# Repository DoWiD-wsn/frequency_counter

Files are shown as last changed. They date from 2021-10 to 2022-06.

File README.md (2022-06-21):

# AVR-based Frequency Counter

The AVR-based frequency counter is partly based on the project developed by [Herbert Dingfelder](http://www.herbert-dingfelder.de/?page_id=304) with some extensions and modifications.
It contains an ATmega8 responsible for measuring the frequency of a square-wave applied to one of four input channels (selectable by software) and acting as a TWI slave (I2C).
With the current design, frequencies of up to 50 MHz are measurable with a precision of 10 Hz.

The AVR-based frequency counter was developed and used as part of the [Embedded Testbench (ETB)](https://github.com/DoWiD-wsn/embedded_testbench) where it was used to measure the frequency stability of the internal clock of microcontroller units of embedded systems under different conditions such as ambient temperature and supply voltage level.

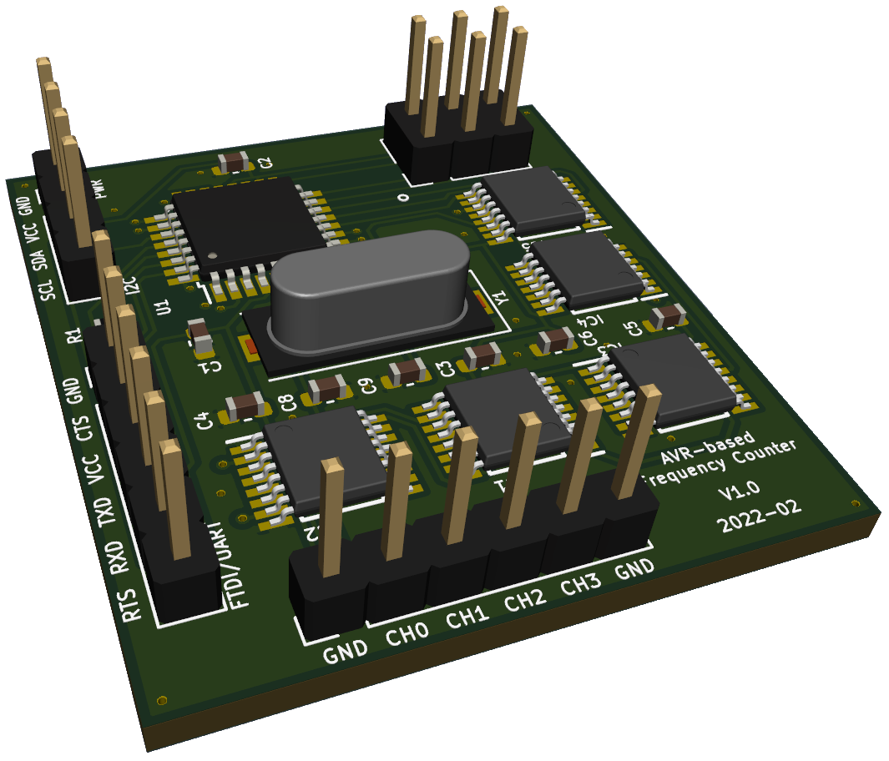
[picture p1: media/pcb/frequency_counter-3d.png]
PCB 3D (/media/pcb/frequency_counter-3d.png)


For more information on the PCB (and its design) refer to [docs/pcb_design.md](docs/pcb_design.md).

## Directory structure

```
.
├── docs                : documents
│   ├── datasheets      : datasheets of used components
│   └── pcb_design.md   : information on the PCB design
├── kicad               : KiCad files
├── media               : Miscellaneous media (images, etc.)
│   ├── evaluation      : Image of a first prototype evaluation
│   ├── i2c             : I2C register format
│   ├── pcb             : Photos and rendered images of the PCB
│   └── schematic       : SVG images of the schematics
└── source              : C code sources for the ATmega8
```

## Contents

* [Description](#description)
* [Built with](#built-with)
* [Preparation](#preparation)
* [I2C Interface](#i2c-interface)
* [Evaluation](#evaluation)
* [Contributors](#contributors)
* [Changelog](#changelog)
* [License](#license)

## Description

**Schematic** (draft):  
Schematic (/media/schematic/frequency_counter-draft.svg)

The ATmega8 is clocked with an external quartz crystal with a frequency of 4.096 MHz.
This clock signal is also used to generate a gate-enable signal for the actual frequency counting stage.
To do so, the 4.096 MHz are first divided by a 74HC4040 with a factor of 2^12 (4096) to get a 1 kHz signal that is further divided by a second 74HC4040 with a factor of 2^8 (256) to have an enable signal with a frequency of 3.90625 Hz (corresponds to an enable time of 128 ms (high level)).

The 74HC153 is used to select between four different input channels.
During the 128 ms long high period of the second 74HC4040, the signal of at the selected input channel is forwarded to the third 74HC4040.
That third 74HC4040 forms together with the ATmega8 the actual counting part, that is, both components together form a 24-bit counter that counts the number of periods of the selected input signal during the 128 ms long enable period.
Thereby, the lower 8-bit (fast portion) are counted by the 74HC4040 and, since the eight bit (Q7) triggers the ATmega8' internal 16-bit counter module, the higher 16-bit are counted internally by the ATmega8.
As the 128 ms enable signal is also connected to the external interrupt (INT0) of the ATmega8, the ATmega8 is "informed" whenever a counting period has finished and can then calculate the corresponding frequency of the input signal.
To do so, the 24-bit counter (lower 8-bit read via GPIOs and the higher 16-bit available interally) show how many periods have passed in the last 128 ms and, thus, allow to easily calculate the resulting frequency.

The measured frequency is output via the UART debug interface (default: 8N1 @9600baud).
As the ATmega8 is configured as an I2C slave (address to be defined in software; default: `0x24`), the result can also be obtained via I2C.
Additionally, the I2C interface can be used to configure the basic operation of the frequency counter such as:

* result resolution (Hz, kHz, or MHz)
* input channel (CH0, CH1, CH2, or CH3)
* sampling rate (no sampling, 3 samples, 5 samples, or 10 samples)

Additionally, the result ready flag can be read indicating whether a result is already available.
In case required, also a counter reset (clearing of all registers) can be requested via I2C.

## Built with

The entire code only depends on the basic AVR libraries (i.e., AVR libc) and can be easily compiled with the AVR GCC.
To upload the binary to the ATmega8, the [AVR-ISP](https://www.mikrocontroller.net/articles/AVR_In_System_Programmer) can be used in combination with [AVRdude](https://www.nongnu.org/avrdude/) or similar.

* [avr-gcc 5.4.0](https://gcc.gnu.org/wiki/avr-gcc) - C code library
* [avr-libc 2.0.0](https://www.nongnu.org/avr-libc/) - C code library

## Preparation

Aside from the hardware circuit, it is important to properly set the fuses of the used ATmega8.
The fuses take care of a basic configuration of the ATmega8, or more precisely, they define the clock source and some interfacing options.
For the AVR-based frequency counter, we choose to have an external crystal oscillator and at startup we will give it some clock cycles to become stable.
As stated in the [ATmega8 datasheet](https://www.microchip.com/wwwproducts/en/ATmega8), we need to have the clock selection fuses `CKSEL` set to `1111` and the start-up times fuses `SUT` set to `11`, resulting in the `low fuse byte` to be set to `0xFF` (Note: the fuse bits are active low, i.e. programmed=0, unprogrammed=1; see also [AVR Fuse Calculator](http://eleccelerator.com/fusecalc/fusecalc.php?chip=atmega8)).

In the `high fuse byte`, we leave the boot size selection bits enabled, i.e., `BOOTSZ` is `00`, and we keep the serial programming and data downloading `SPIEN` enabled (otherwise we would not be able to use the [AVR ISP](https://www.mikrocontroller.net/articles/AVR_In_System_Programmer) to flash our firmware).
Additionally, we need to program the oscillator options fuse `CKOPT` to `0` to switch the crystal from weak amplitude to full amplitude required to clock the [74HC4040](https://www.ti.com/product/SN74HC4040) counter.
As a result, we need to set the `high fuse byte` to `0xC9`.

The fuse bit values and the resulting bit pattern as well as the corresponding [AVRDUDE](https://www.nongnu.org/avrdude/) commands can be derived with one of the available [online fuse calculator](https://www.engbedded.com/fusecalc/).
In our case, the resulting AVRDUDE arguments are:  
  `-U lfuse:w:0xff:m -U hfuse:w:0xc9:m`

## I2C Interface

The AVR-based frequency counter can be used as an I2C slave.
The I2C address can be defined in software (default: 0x24).

Basically, there are four 8-bit registers available and accessible via I2C, that are:

1. Configuration register `CONFIG` (address: `0x00`; R/W)
2. Frequency LSB register `FREQ-LSB` (address: `0x01`; R)
3. Frequency MSB register `FREQ-MSB` (address: `0x02`; R)
4. Frequency extended MSB register `FREQ-XMSB` (address: `0x03`; R)

As can be seen, all registers can be read but only the `CONFIG` register allows overwriting its value; the measured frequency value can only be read.

With the `CONFIG` register, the basic operation of the frequency counter can be defined, that is, requesting a software reset, checking the result ready flag, setting the sampling rate, defining the frequency resolution, and selecting the input channel (see figure below).
The default value of the `CONFIG` register is `0x00`.

Prototype (/media/i2c/i2c_reg-config.svg)

### Reset request

The reset request bit can be used to cause a software reset of the frequency counter, that is, all counter modules and internal counter values are reset.
The configuration is not changed.

| `RST` | Effect |
|---|---|
| `0` | no effect |
| `1` | request reset |

### Result ready

The result ready flag indicates whether a frequency measurement is ready to be read.

| `RDY` | Meaning |
|---|---|
| `0` | result not available |
| `1` | result available |

### Result sampling

The frequency counter offers to possibility to sample several measurements and provide the mean average to have more stable results.
Thereby, one of four different sampling options can be selected.

| `SMP1` | `SMP0` | Sampling |
|---|---|---|
| `0` | `0` | no sampling |
| `0` | `1` | 3 samples |
| `1` | `0` | 5 samples |
| `1` | `1` | 10 samples |

### Result resolution

The resulting frequency can be read in three different resolution.

| `RES1` | `RES0` | Resolution (result width) |
|---|---|---|
| `0` | `0` | Hz (24 bit: LSB+MSB+XMSB) |
| `0` | `1` | kHz (16 bit: LSB+MSB) |
| `1` | `0` | MHz (8 bit: LSB) |
| `1` | `1` | reserved |

### Input channel selection

With the `CHSEL` bits, the input channel can be selected, that is, the channel that is latched through by the 4-to-1 multiplexer.

| `CHSEL1` | `CHSEL0` | Channel |
|---|---|---|
| `0` | `0` | CH0 |
| `0` | `1` | CH1 |
| `1` | `0` | CH2 |
| `1` | `1` | CH3 |

## Evaluation

The concept was evaluated based on a prototype as shown below.
In this prototype, the multiplexer was neglected and the input signal was connected to the counting stage via a jumper.

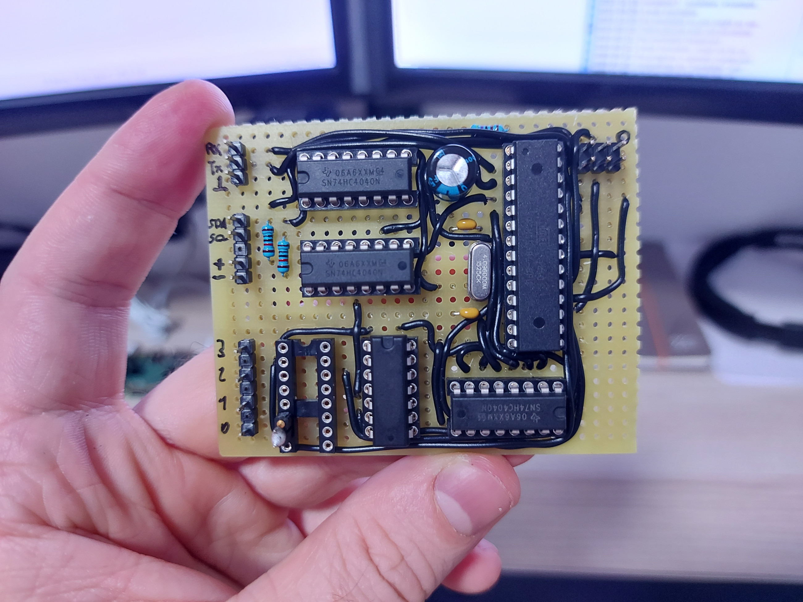
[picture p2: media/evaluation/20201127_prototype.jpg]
Prototype (/media/evaluation/20201127_prototype.jpg)


To check the proper functioning of the prototype, a second microcontroller was used that output its internal clock source via a GPIO pin (the AVR offer to output the clock source to a GPIO named `CLKO`).
In this test setup, the clock source of the microcontroller under test was changed every few seconds between four different clock options:

1. internal 8MHz RC oscillator (Fcpu = 8MHz)
2. internal 8MHz RC oscillator with a prescaler of 8 (Fcpu = 1MHz)
3. external 16MHz quartz oscillator (Fcpu = 16MHz)
4. external 16MHz quartz oscillator with a prescaler of 8 (Fcpu = 2MHz)

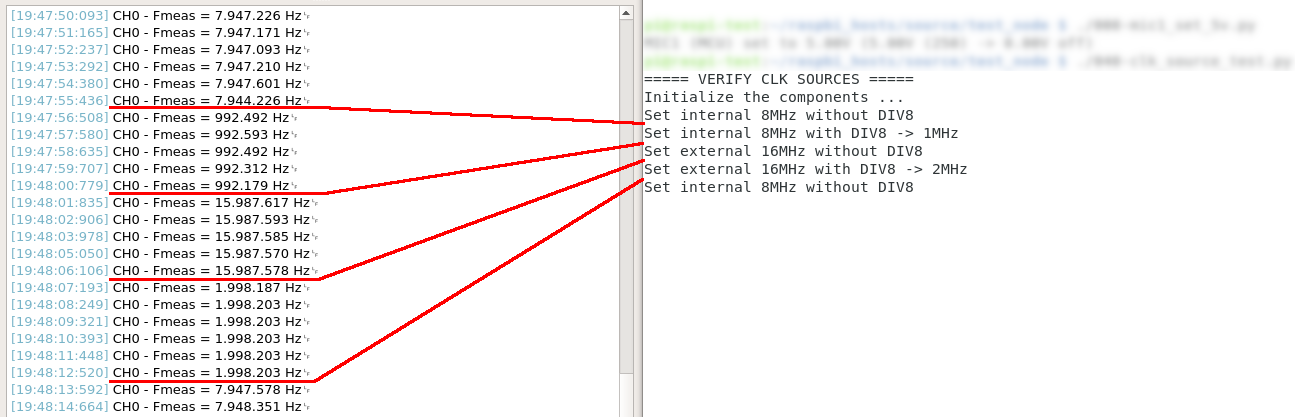
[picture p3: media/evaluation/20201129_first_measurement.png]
Prototype (/media/evaluation/20201129_first_measurement.png)


These measurements were confirmed with an oscilloscope that also measured the frequency.
Thereby, the expected accuracy of 10Hz could be confirmed.

## Contributors

* **Dominik Widhalm** - [***DC-RES***](https://informatics.tuwien.ac.at/doctoral/resilient-embedded-systems/) - [*UAS Technikum Wien*](https://embsys.technikum-wien.at/staff/widhalm/)

Contributions of any kind to improve the project are highly welcome.
For coding bugs or minor improvements simply use pull requests.
However, for major changes or general discussions please contact [Dominik Widhalm](mailto:widhalm@technikum-wien.at?subject=frequency%20counter%20on%20GitHub).

## Changelog

A list of prior versions and changes between the updates can be found inn the [CHANGELOG.md](CHANGELOG.md) file.
Note that the major and minor number refer to the hardware version of the ASN(x) board while the patch version is used to denote subsequent software versions.

## License

This project is licensed under the MIT License - see the [LICENSE.md](LICENSE.md) file for details.

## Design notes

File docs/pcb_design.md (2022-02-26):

# ASN(x) - PCB Design

The board was designed with KiCad `version 5.1.9` and mainly uses schematic symbols and PCB footprints available in the [KiCad libraries](https://kicad.org/libraries/download/).
Parts not included in these libraries are available as project-specific libraries (see below).
The design requires only a two-layer PCB with all components placed on the top side.

## Contents

```
kicad/
├── 3dshapes                        : 3D models of PCB parts
├── myfootprint.pretty              : custom PCB footprints
├── bom                             : interactive HTML BOM
├── frequency_counter.kicad_pcb     : PCB layout file
├── frequency_counter.pro           : KiCad project file
├── frequency_counter.sch           : schematic layout file
├── fp-lib-table                    : project-specific footprint library list
├── mysymbols.dcm                   : custom symbol library (descriptions, aliases and keywords)
├── mysymbols.lib                   : custom symbol library
└── sym-lib-table                   : project-specific symbol library list
```

## Schematic

**Schematic**:  
Schematic (/media/schematic/frequency_counter.svg)

## PCB Design

Front:  
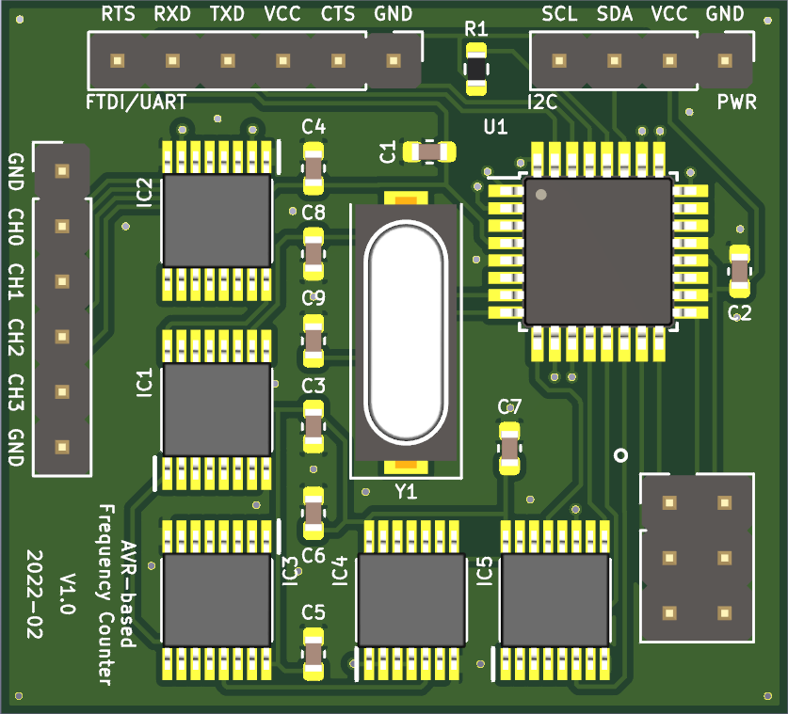
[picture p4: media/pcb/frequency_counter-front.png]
PCB front (/media/pcb/frequency_counter-front.png)


Back:  
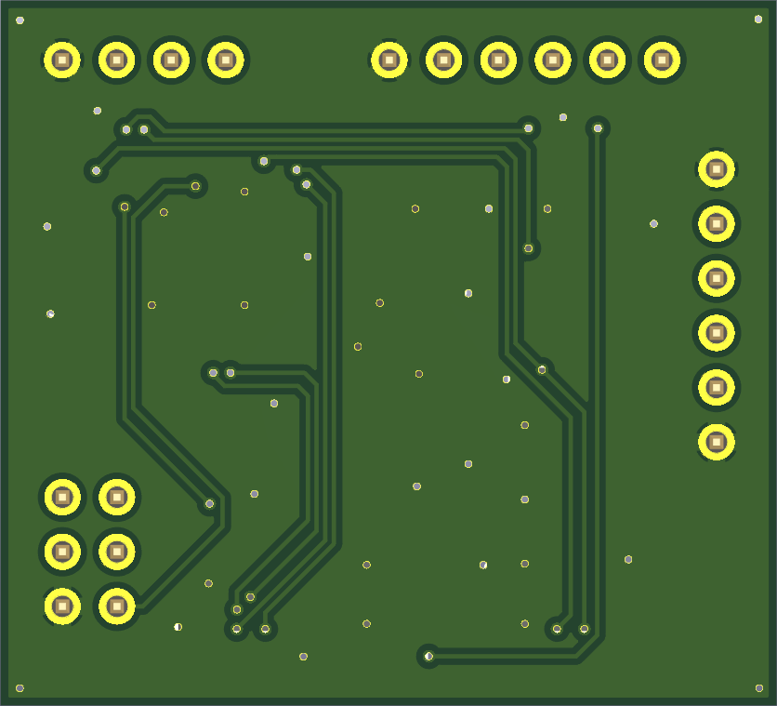
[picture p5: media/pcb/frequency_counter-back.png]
PCB back (/media/pcb/frequency_counter-back.png)


For the PCB design the following rules were used:
* Design rules:
    * Minimum track width: `0.15 mm`
    * Minimum via diameter: `0.6 mm`
    * Minimum via drill: `0.3 mm`
    * Minimum hole to hole: `0.25 mm`
    * `Prohibit overlapping courtyards`
* Tracks:
    * `0.2 mm`
    * `0.25 mm`
    * `0.4 mm`
    * `0.8 mm`
* Vias:
    * Size: `0.6 mm`
    * Drill: `0.3 mm`
* Zones:
    * Clearance: `0.3 mm`
    * Minimum width: `0.18 mm`
    * Pad connections: `Thermal reliefs`
    * Thermal clearance: `0.18 mm`
    * Thermal spoke width: `0.8 mm`

## Components and Libraries

An interactive BOM can be found in the `/kicad/bom/` directory (see [here](../kicad/bom/frequency_counter.html); created with [InteractiveHtmlBom](https://github.com/openscopeproject/InteractiveHtmlBom)).

| Reference | Value | Symbol Library | Symbol | Footprint Library | Footprint | Dist. |
|---|---|---|---|---|---|---|
| C8-C9 | 18pF  | Device | C | Capacitor_SMD | C_0603_1608Metric | [Farnell](https://at.farnell.com/kemet/c0603c180k5ractu/kondensator-18pf-50v-10-x7r-0603/dp/2821151) |
| C1-C7 | 100nF | Device | C | Capacitor_SMD | C_0603_1608Metric | [Farnell](https://at.farnell.com/kemet/c0603c104m5ractu/kondensator-0-1-f-50v-20-x7r-0603/dp/2581046) |
| R1 | 4k7 | Device | R | Resistor_SMD | R_0603_1608Metric | [Farnell](https://at.farnell.com/yageo/ac0603fr-074k7l/dickschichtwiderstand-4k7-1-0/dp/3495274) |
| U1 | - | MCU_Microchip_ATmega | ATmega8-16AU | Package_QFP | TQFP-32_7x7mm_P0.8mm | [Farnell](https://at.farnell.com/microchip/atmega8-16au/8bit-8k-flash-mcu-smd-tqfp32/dp/9171371) |
| IC1,IC3,IC5 | - | *mysymbols*`*` | SN74HC4040PW | *myfootprint*`*` | SOP65P640X120-16N | [Farnell](https://at.farnell.com/texas-instruments/sn74hc4040pw/logic-counter-async-binary-16tssop/dp/3119823) |
| IC2 | - | *mysymbols*`*` | SN74HC153PW  | *myfootprint*`*` | SOP65P640X120-16N | [Farnell](https://at.farnell.com/texas-instruments/sn74hc153pw/logic-selector-mux-dual-4-1-16tssop/dp/3121093) |
| IC4 | - | *mysymbols*`*` | SN74HC00PW | *myfootprint*`*` | SOP65P640X120-14N | [Farnell](https://at.farnell.com/texas-instruments/sn74hc00pwr/ic-quad-2input-nand-smd-74hc00/dp/3120421) |
| Y1 | 4.096MHz  | Device | Crystal | Crystal | Crystal_SMD_HC49-SD | [Farnell](https://at.farnell.com/vishay/xt9m20ana4m096/quarz-4-096mhz-at-modus-hc49-4hsmx/dp/1611766) |
| J1 | - | Connector_Generic | Conn_01x04 | Connector_PinHeader_2.54mm | PinHeader_1x04_P2.54mm_Vertical | [Farnell](https://at.farnell.com/wurth-elektronik/61304011121/stiftleiste-2-54mm-tht-vertikal/dp/2356175) |
| J2-J3 | - | Connector_Generic | Conn_01x06 | Connector_PinHeader_2.54mm | PinHeader_1x06_P2.54mm_Vertical | [Farnell](https://at.farnell.com/wurth-elektronik/61304011121/stiftleiste-2-54mm-tht-vertikal/dp/2356175) |
| J4 | - | Connector | AVR-ISP-6 | Connector_PinHeader_2.54mm | PinHeader_2x03_P2.54mm_Vertical | [Farnell](https://at.farnell.com/wurth-elektronik/61304021121/stiftleiste-2-54mm-tht-vertikal/dp/2356148) |

If your installation of KiCad is missing (some of) the standard libraries, you can download them from [KiCad libraries](https://kicad.org/libraries/download/).
The custom libraries required (marked with `*`) are all contained in this repository.

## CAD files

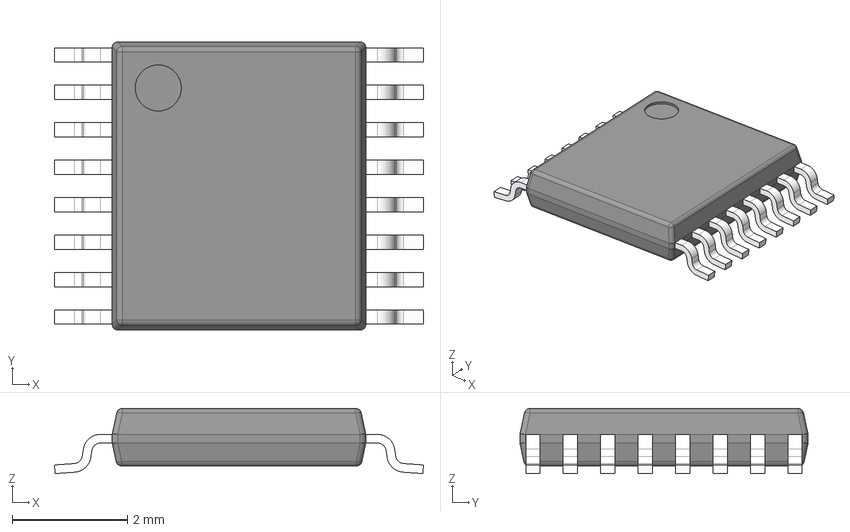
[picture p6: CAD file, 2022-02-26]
kicad/3dshapes/SN74HC153PW.stp
6.40 x 5.00 x 1.13 mm
BODY-TSSOP
LEAD-TSSOP x 16
PIN1

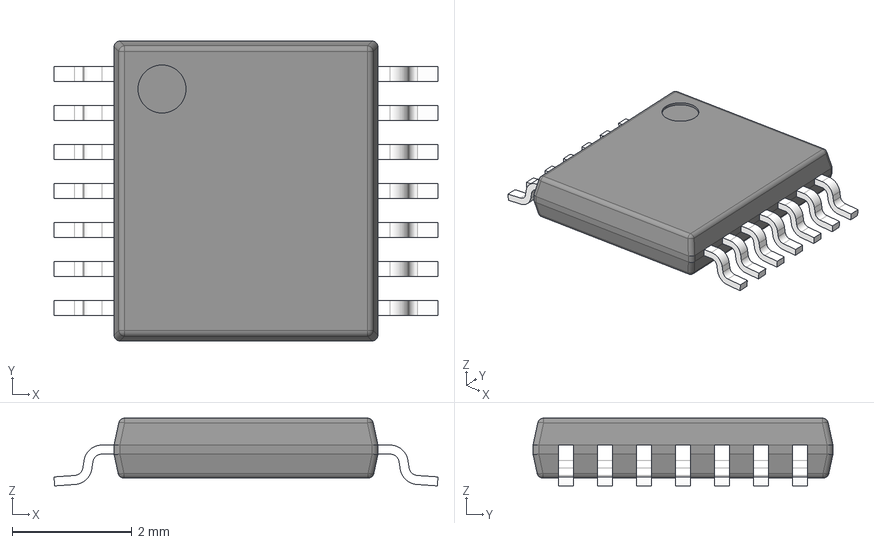
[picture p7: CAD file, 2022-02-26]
kicad/3dshapes/SN74HC00PW.stp
6.40 x 5.00 x 1.13 mm
BODY-TSSOP
LEAD-TSSOP x 14
PIN1

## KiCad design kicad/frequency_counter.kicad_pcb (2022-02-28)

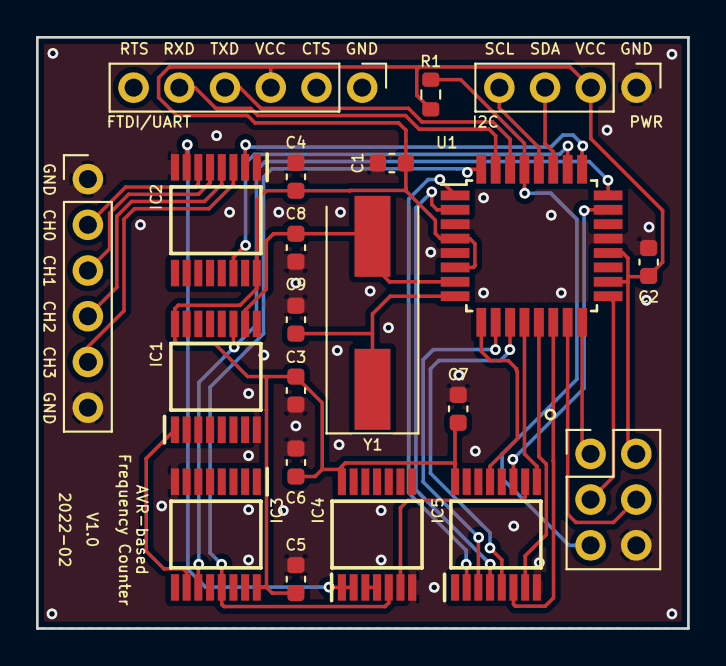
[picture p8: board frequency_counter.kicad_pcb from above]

Board: 2 copper layers, 36.2 x 32.8 mm, 21 parts (0 on the bottom side), 33 nets.

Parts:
C1, C2, C3, C4, C5, C6, C7: 100n; C_0603_1608Metric
C8, C9: 18p; C_0603_1608Metric
IC1, IC3, IC5: SN74HC4040PW; SOP65P640X120-16N
IC2: SN74HC153PW; SOP65P640X120-16N
IC4: SN74HC00PW; SOP65P640X120-14N
J1: PWR/I2C; PinHeader_1x04_P2.54mm_Vertical
J2: FTDI; PinHeader_1x06_P2.54mm_Vertical
J3: Input; PinHeader_1x06_P2.54mm_Vertical
J4: AVR-ISP-6; PinHeader_2x03_P2.54mm_Vertical
R1: 4k7; R_0603_1608Metric
U1: ATmega8-16AU; TQFP-32_7x7mm_P0.8mm
Y1: 4.096M; Crystal_SMD_HC49-SD

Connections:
+5V: C1.2, C2.2, C3.2, C4.2, C5.2, C6.2, C7.2, IC1.16, IC2.16, IC3.16, IC4.14, IC5.16, J1.2, J2.3, J4.2, R1.1, U1.4, U1.6, U1.18, U1.20
/1K: IC1.1, IC3.10
/4M: C8.1, IC1.10, U1.7, Y1.2
/CLK: IC4.6, IC5.10
/GATE: IC3.13, IC4.5, U1.32
/MISO: J4.1, U1.16
/MOSI: J4.4, U1.15
/PB0: IC5.9, U1.12
/PB1: IC5.7, U1.13
/PB2: IC5.6, U1.14
/PC0: IC5.11, U1.23
/PC1: IC1.11, IC3.11, U1.24
/PC2: IC2.2, U1.25
/PC3: IC2.14, U1.26
/PD3: IC5.2, U1.1
/PD4: IC5.4, U1.2
/PD6: IC5.3, U1.10
/PD7: IC5.5, U1.11
/RST: J4.5, R1.2, U1.29
/RXD: J2.4, U1.30
/SCK: J4.3, U1.17
/SCL: J1.4, U1.28
/SDA: J1.3, U1.27
/T1: IC5.13, U1.9
/TXD: J2.5, U1.31
/Y: IC2.7, IC4.1, IC4.2
GND: C1.1, C2.1, C3.1, C4.1, C5.1, C6.1, C7.1, C8.2, C9.2, IC1.8, IC2.1, IC2.8, IC3.8, IC4.7, IC5.8, J1.1, J2.1, J3.1, J3.6, J4.6, U1.3, U1.5, U1.21
unnamed: C9.1, U1.8, Y1.1
unnamed: IC2.3, J3.5
unnamed: IC2.4, J3.4
unnamed: IC2.5, J3.3
unnamed: IC2.6, J3.2
unnamed: IC4.3, IC4.4

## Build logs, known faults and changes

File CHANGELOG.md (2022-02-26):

# Changelog
All notable changes to this project will be documented in this file.

The format is based on [Keep a Changelog](https://keepachangelog.com/en/1.0.0/), and this project adheres to [Semantic Versioning](https://semver.org/spec/v2.0.0.html).
However, the major and minor number are used to express the version of the hardware platform while the patch version expresses additional revision of software modules only.

## [dev]
### Added
### Changed
### Removed

## [0.2] - 2022-02-27
### Added
- Initial PCB design

## [0.1] - 2021-10-15
### Added
- First design of the frequency counter
- Initial documentation
- Initial AVR code (not fully tested yet)

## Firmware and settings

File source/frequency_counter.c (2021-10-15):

/**********************************************************************
 *  AVR-BASED FREQUENCY COUNTER                                       *
 *                                                                    *
 *  Author: Dominik Widhalm                                           *
 *  Date:   2020-11-29                                                *
 *                                                                    *
 *  Brief:                                                            *
 *      Frequency counter based on an AVR ATmega8. The MCU is clocked *
 *      by an 4.096MHz crystal whose oscillation also driven a        *
 *      prescaler circuit based on 74HC4040 to generate a 128ms       *
 *      enable signal for the frequency measurement using a 74HC00.   *
 *      During on enable-period the oscillations of the input channel *
 *      are counted by another 74HC4040 where the 8th digit drives    *
 *      the timer/counter module 1 (16 bit) of the ATmega8, creating  *
 *      a cascaded 24-bit counter (16 bit intern + 8 bit extern).     *
 *      Additionally, the switching of the enable signal triggers     *
 *      an external interrupt of the ATmega8 telling the AVR when a   *
 *      sample period has finished. After that, the AVR simply takes  *
 *      the 24 bit and calculates the corresponding frequency.        *
 *      The result can be read via I2C (AVR acts as a slave).         *
 *      Additionally, some configurations like the input channel can  *
 *      also be set via I2C commands.                                 *
 *                                                                    *
 *  I2C Register:                                                     *
 *      0x00 - CONFIG (R/W):                                          *
 *      |RST|RDY|SMP1|SMP0|RES1|RES0|CHSEL1|CHSEL0|                   *
 *      0x01 - FREQ-LSB (R):                                          *
 *      |LSB7|LSB6|LSB5|LSB4|LSB3|LSB2|LSB1|LSB0|                     *
 *      0x02 - FREQ-MSB (R):                                          *
 *      |MSB7|MSB6|MSB5|MSB4|MSB3|MSB2|MSB1|MSB0|                     *
 *      0x03 - FREQ-XMSB (R):                                         *
 *      |XMSB7|XMSB6|XMSB5|XMSB4|XMSB3|XMSB2|XMSB1|XMSB0|             *
 *                                                                    *
 *      Description:                                                  *
 *      -RST- Reset                                                   *
 *        0   nothing                                                 *
 *        1   request reset                                           *
 *      -RDY- Result Ready                                            *
 *        0   no measurement result                                   *
 *        1   measurement result  available                           *
 *      -SMP1-SMP0- Sampling                                          *
 *        0    0    no sampling (1)                                   *
 *        0    1    3 samples                                         *
 *        1    0    5 samples                                         *
 *        1    1    10 samples                                        *
 *      -RES1-RES0- Resolution                                        *
 *        0    0    Hz        (24 bit -> LSB + MSB + XMSB)            *
 *        0    1    kHz       (16 bit -> LSB + MSB)                   *
 *        1    0    MHz       (8 bit  -> LSB)                         *
 *        1    1    reserved                                          *
 *      -CHSEL1-CHSEL0- Channel Selection                             *
 *         0      0     CH0                                           *
 *         0      1     CH1                                           *
 *         1      0     CH2                                           *
 *         1      1     CH3                                           *
 *                                                                    *
 *  Resources:                                                        *
 *  -) Frequency counter:                                             *
 *     www.herbert-dingfelder.de/?page_id=304                         *
 *  -) I2C Slave:                                                     *
 *     rn-wissen.de/wiki/index.php/TWI_Slave_mit_avr-gcc              *
 *     pc.gameactive.org/i2cslavetutorial/I2C_SlaveTutorial.html      *
 *                                                                    *
 *  Note:                                                             *
 *  -) Writing config works ... reading data not yet!                 *
 *                                                                    *
 **********************************************************************/

/*** Enable Debugging (UART@9600) ***/
#define DEBUG_UART_ENABLE           (1)


/***** INCLUDES *******************************************************/
#include <math.h>
#include <avr/io.h>
#include <avr/interrupt.h>
#include <util/delay.h>
#include <util/twi.h>

/* Invoke UART library if debugging is enabled */
#if DEBUG_UART_ENABLE
# include "uart.h"
#endif


/***** DEFINES ********************************************************/
/*** I2C ***/
/* Slave Address */
#define I2C_SLAVE_ADDRESS           (0x24)
/* Register Addresses */
#define I2C_REG_CONFIG              (0x00)
#define I2C_REG_MSB                 (0x01)
#define I2C_REG_LSB                 (0x02)
#define I2C_REG_XLSB                (0x03)
#define I2C_REG_UNDEF               (0xFF)
/* Config Register Bits */
#define I2C_CONFIG_RST              (7)
#define I2C_CONFIG_RST_MASK         (0x80)
#define I2C_CONFIG_RDY              (6)
#define I2C_CONFIG_RDY_MASK         (0x40)
#define I2C_CONFIG_SMP              (4)
#define I2C_CONFIG_SMP_MASK         (0x30)
#define I2C_CONFIG_RES              (2)
#define I2C_CONFIG_RES_MASK         (0x0C)
#define I2C_CONFIG_CHSEL            (0)
#define I2C_CONFIG_CHSEL_MASK       (0x03)

/*** I2C slave responses ***/
/* ACK      -> TWEN, TWIE, TWINT, TWEA */
#define TWCR_ACK                    (0xC5)
/* NACK     -> TWEN, TWIE, TWINT */
#define TWCR_NACK                   (0x85)
/* RESET    -> TWEN, TWIE, TWINT, TWEA, TWSTO */
#define TWCR_RESET                  (0xD5)

/*** Control GPIO ***/
/* Prescaler-Counter Reset */
#define GPIO_PRESCALER_RST_DDR      (DDRC)
#define GPIO_PRESCALER_RST_PORT     (PORTC)
#define GPIO_PRESCALER_RST_PIN      (PINC)
#define GPIO_PRESCALER_RST          _BV(PC1)
/* Frequency-Counter Reset */
#define GPIO_CNT_RST_DDR            (DDRC)
#define GPIO_CNT_RST_PORT           (PORTC)
#define GPIO_CNT_RST_PIN            (PINC)
#define GPIO_CNT_RST                _BV(PC0)
/* MUX Select */
#define GPIO_MUX_DDR                (DDRC)
#define GPIO_MUX_PORT               (PORTC)
#define GPIO_MUX_PIN                (PINC)
#define GPIO_MUX_S0                 _BV(PC3)
#define GPIO_MUX_S1                 _BV(PC2)

/*** Gate-enable Clock ***/
#define GPIO_GATE_EN_DDR            (DDRD)
#define GPIO_GATE_EN_PORT           (PORTD)
#define GPIO_GATE_EN_PIN            (PIND)
#define GPIO_GATE_EN                _BV(PD2)

/*** Frequency Counter Value ***/
/* Q7 (T1) */
#define GPIO_CNT_Q7_DDR             (DDRD)
#define GPIO_CNT_Q7_PORT            (PORTD)
#define GPIO_CNT_Q7_PIN             (PIND)
#define GPIO_CNT_Q7                 _BV(PD5)
/* Q6 */
#define GPIO_CNT_Q6_DDR             (DDRD)
#define GPIO_CNT_Q6_PORT            (PORTD)
#define GPIO_CNT_Q6_PIN             (PIND)
#define GPIO_CNT_Q6                 _BV(PD4)
/* Q5 */
#define GPIO_CNT_Q5_DDR             (DDRD)
#define GPIO_CNT_Q5_PORT            (PORTD)
#define GPIO_CNT_Q5_PIN             (PIND)
#define GPIO_CNT_Q5                 _BV(PD3)
/* Q4 */
#define GPIO_CNT_Q4_DDR             (DDRD)
#define GPIO_CNT_Q4_PORT            (PORTD)
#define GPIO_CNT_Q4_PIN             (PIND)
#define GPIO_CNT_Q4                 _BV(PD6)
/* Q3 */
#define GPIO_CNT_Q3_DDR             (DDRD)
#define GPIO_CNT_Q3_PORT            (PORTD)
#define GPIO_CNT_Q3_PIN             (PIND)
#define GPIO_CNT_Q3                 _BV(PD7)
/* Q2 */
#define GPIO_CNT_Q2_DDR             (DDRB)
#define GPIO_CNT_Q2_PORT            (PORTB)
#define GPIO_CNT_Q2_PIN             (PINB)
#define GPIO_CNT_Q2                 _BV(PB2)
/* Q1 */
#define GPIO_CNT_Q1_DDR             (DDRB)
#define GPIO_CNT_Q1_PORT            (PORTB)
#define GPIO_CNT_Q1_PIN             (PINB)
#define GPIO_CNT_Q1                 _BV(PB1)
/* Q0 */
#define GPIO_CNT_Q0_DDR             (DDRB)
#define GPIO_CNT_Q0_PORT            (PORTB)
#define GPIO_CNT_Q0_PIN             (PINB)
#define GPIO_CNT_Q0                 _BV(PB0)


/***** GLOBAL VARIABLES ***********************************************/
/* Data Array */
uint8_t i2c_data[4] = {0,0,0,0};
/* I2C pointer positions */
uint8_t i2c_data_pos = I2C_REG_UNDEF;
/* Pointer to data register */
uint8_t *config = &i2c_data[0];
uint8_t *lsb    = &i2c_data[1];
uint8_t *msb    = &i2c_data[2];
uint8_t *xmsb   = &i2c_data[3];


/***** LOCAL FUNCTION PROTOTYPES **************************************/
/* Init functions */
void gpio_init(void);
void timer1_init(void);
void extint_init(void);
void counter_init(void);
void i2c_slave_init(uint8_t address);

/* MUX functions */
void mux_select(uint8_t ch);

/* Helper functions */
uint8_t cnt_read_lsb(void);
void cnt_reset_lsb(void);


/***** INTERRUPT SERVICE ROUTINES (ISR) *****/
/* External Interrupt (INT0 falling edge) */
ISR(INT0_vect) {
    uint32_t cnt=0;
    /* Read the lower (external) 8 bit */
    cnt = (uint32_t)cnt_read_lsb();
    /* Read the higher (internal) 16 bit */
    cnt |= (uint32_t)(TCNT1L)<<8;
    cnt |= (uint32_t)(TCNT1H)<<16;
    /* Reset the external counter */
    cnt_reset_lsb();
    /* Reset the internal counter */
    TCNT1H = 0;
    TCNT1L = 0;
    /* Calculate resulting frequency (disable IRS meanwhile) */
    uint32_t frequency = (cnt*1000)>>7;
    uint8_t resolution = (*config & I2C_CONFIG_RES_MASK) >> I2C_CONFIG_RES;
    cli();
    switch(resolution) {
        /*** Hz ***/
        case 0:
            /* Copy result */
            *lsb  = (frequency & 0x000000FF);
            *msb  = (frequency & 0x0000FF00)>>8;
            *xmsb = (frequency & 0x00FF0000)>>16;
            /* Result is available */
            *config |= _BV(I2C_CONFIG_RDY);
            break;
        /*** kHz ***/
        case 1:
            /* Scale result */
            frequency = (uint32_t)(round((double)frequency/1000.0));
            /* Copy result */
            *lsb  = (frequency & 0x000000FF);
            *msb  = (frequency & 0x0000FF00)>>8;
            *xmsb = 0x00;
            /* Result is available */
            *config |= _BV(I2C_CONFIG_RDY);
            break;
        /*** MHz ***/
        case 2:
            /* Scale result */
            frequency = (uint32_t)(round((double)frequency/1000000.0));
            /* Copy result */
            *lsb  = (frequency & 0x000000FF);
            *msb  = 0x00;
            *xmsb = 0x00;
            /* Result is available */
            *config |= _BV(I2C_CONFIG_RDY);
            break;
        /*** Reserved ***/
        default:
            /* Clear result bytes */
            *lsb  = 0x00;
            *msb  = 0x00;
            *xmsb = 0x00;
            /* No result is available */
            *config &= ~_BV(I2C_CONFIG_RDY);
    };
    sei();
}

/* I2C interrupt service (see AVR311 for more detail) */
ISR(TWI_vect) {
    /* Temporary variable for received data */
    uint8_t data = 0;
    
    /*** DBG ***/ uart_puts("\nSTATUS ");uart_print_hex(TW_STATUS);uart_puts("\n");
    
    /* Slave's reaction depends on status register value */
    switch(TW_STATUS) {
        /*** Slave Receiver ***/
        
        /* 0x60 - Own SLA+W has been received; ACK has been returned */
        case TW_SR_SLA_ACK:
        /* 0x68 - Arbitration lost in SLA+R/W as mater; own SLA+W has been received; ACK has been returned */
        case TW_SR_ARB_LOST_SLA_ACK:
            /*** DBG ***/ uart_puts("TW_SR_SLA_ACK\n");
            /* Set positions to "undef" */
            i2c_data_pos = I2C_REG_UNDEF;
            /* Data byte will be received and ACK will be returned */
            TWCR = TWCR_ACK;
            break;
        
        /* 0x70 - General call address has been received; ACK has been returned */
        //case TW_SR_GCALL_ACK:
        /* 0x78 - Arbitration lost in SLA+R/W as Master; General call address has been received; ACK has been returned */
        //case TW_SR_ARB_LOST_GCALL_ACK:
        /* 0x90 - Previously addressed with general call; data has been received; ACK has been returned */
        //case TW_SR_GCALL_DATA_ACK:
        /* 0x98 - Previously addressed with general call; data has been received; NOT ACK has been returned */
        //case TW_SR_GCALL_DATA_NACK:
        
        /* 0x80 - Previously addressed with own SLA+W; data has been received; ACK has been returned */
        case TW_SR_DATA_ACK:
            /* Read the received byte */
            data = TWDR;
            /* Check if the read position is "undef" (first access) */
            if(i2c_data_pos == I2C_REG_UNDEF) {
                /*** DBG ***/ uart_puts("TW_SR_DATA_ACK-1 ");uart_print_hex(TWDR);uart_puts("\n");
                /* Set the data array position to the requested position */
                i2c_data_pos = data;
                /* Respond with ACK to wait for next data byte (value) */
                TWCR = TWCR_ACK;
            /* Write position has already been set - ready to receive data */
            } else {
                /* Check if previously requested register address is valid (only config can be written) */
                if(i2c_data_pos == I2C_REG_CONFIG) {
                    /*** DBG ***/ uart_puts("TW_SR_DATA_ACK-3 ");uart_print_hex(TWDR);uart_puts("\n");
                    /* Check which bits have changed */
                    uint8_t delta = *config ^ data;
                    /* Check if a reset was requested */
                    if(delta & I2C_CONFIG_RST_MASK) {
                        /* Reset the counter */
                        counter_init();
                        /* Reset the RDY flag */
                        *config &= ~_BV(I2C_CONFIG_RDY);
                        /* Clear the result bytes */
                        *lsb = 0x00;
                        *msb = 0x00;
                        *xmsb = 0x00;
                    }
                    /* Check if the sampling has changed */
                    if(delta & I2C_CONFIG_SMP_MASK) {
                        /* Reset the RDY flag */
                        *config &= ~_BV(I2C_CONFIG_RDY);
                        /* Clear the result bytes */
                        *lsb = 0x00;
                        *msb = 0x00;
                        *xmsb = 0x00;
                        /* Copy the new resolution selection */
                        *config = (*config & ~I2C_CONFIG_SMP_MASK) | (data & I2C_CONFIG_SMP_MASK);
                    }
                    /* Check if the resolution has changed */
                    if(delta & I2C_CONFIG_RES_MASK) {
                        /* Reset the RDY flag */
                        *config &= ~_BV(I2C_CONFIG_RDY);
                        /* Clear the result bytes */
                        *lsb = 0x00;
                        *msb = 0x00;
                        *xmsb = 0x00;
                        /* Copy the new resolution selection */
                        *config = (*config & ~I2C_CONFIG_RES_MASK) | (data & I2C_CONFIG_RES_MASK);
                    }
                    /* Check if the channel has changed */
                    if(delta & I2C_CONFIG_CHSEL_MASK) {
                        /* Set the new channel */
                        mux_select((delta & I2C_CONFIG_CHSEL_MASK)>>I2C_CONFIG_CHSEL);
                        /* Reset the RDY flag */
                        *config &= ~_BV(I2C_CONFIG_RDY);
                        /* Clear the result bytes */
                        *lsb = 0x00;
                        *msb = 0x00;
                        *xmsb = 0x00;
                        /* Copy the new channel selection */
                        *config = (*config & ~I2C_CONFIG_CHSEL_MASK) | (data & I2C_CONFIG_CHSEL_MASK);
                    }
                    /* Operation finished */
                    i2c_data_pos = I2C_REG_UNDEF;
                    /* Respond with NACK */
                    TWCR = TWCR_NACK;
                } else {
                    /*** DBG ***/ uart_puts("TW_SR_DATA_ACK-2 ");uart_print_hex(TWDR);uart_puts("\n");
                    
                    /* Invalid request */
                    i2c_data_pos = I2C_REG_UNDEF;
                    /* Respond with NACK */
                    TWCR = TWCR_NACK;
                }
            }
            break;
        
        /* 0x88 - Previously addressed with own SLA+W; data has been received; NOT ACK has been returned */
        case TW_SR_DATA_NACK:
        /* 0xA0 - A STOP condition or repeated START condition has been received while still addressed as slave */
        case TW_SR_STOP:
            /*** DBG ***/ uart_puts("TW_SR_STOP\n");
            /* Respont with ACK */
            TWCR = TWCR_ACK;
            break;
        
        
        /*** Slave Transmitter ***/
        
        /* 0xA8 - Own SLA+R has been received; ACK has been returned */
        case TW_ST_SLA_ACK:
        /* 0xB0 - Arbitration lost in SLA+R/W as Master; own SLA+R has been received; ACK has been returned */
        case TW_ST_ARB_LOST_SLA_ACK:
        /* 0xB8 - Data byte in TWDR has been transmitted; ACK has been received */
        case TW_ST_DATA_ACK:
            /*** DBG ***/ uart_puts("TW_ST_SLA_ACK");uart_print_hex(TWDR);uart_puts("\n");
            /* Check if data position is valid */
            if(i2c_data_pos != I2C_REG_UNDEF) {
                /*** DBG ***/ uart_puts("TW_ST_SLA_ACK-1\n");
                /* Check if read pointer is set to CONFIG (no consecutive read) */
                if(i2c_data_pos == I2C_REG_CONFIG) {
                    /* Copy the config register content */
                    TWDR = *config;
                    /* Operation finished */
                    i2c_data_pos = I2C_REG_UNDEF;
                    /* Respond with NACK */
                    TWCR = TWCR_NACK;
                } else {
                    /* Copy addressed result byte */
                    TWDR = i2c_data[i2c_data_pos];
                    /* Check if there is still data to read */
                    if(i2c_data_pos < I2C_REG_XLSB) {
                        /* Increment read position */
                        i2c_data_pos++;
                        /* Send ACK */
                        TWCR = TWCR_ACK;
                    } else {
                        /* No more data left */
                        i2c_data_pos = I2C_REG_UNDEF;
                        /* Respond with NACK */
                        TWCR = TWCR_NACK;
                    }
                }
            } else {
                /*** DBG ***/ uart_puts("TW_ST_SLA_ACK-2\n");
                /* Respond with NACK */
                TWCR = TWCR_NACK;
            }
            break;
        
        /* 0xC0 - Data byte in TWDR has been transmitted; NOT ACK has been received */
        case TW_ST_DATA_NACK:
        /* 0xC8 - Last data byte in TWDR has been transmitted; ACK has been received */
        case TW_ST_LAST_DATA:
            /* Respont with ACK */
            TWCR = TWCR_ACK;
            break;
        
        
        /*** Misc ***/
        
        /* 0xF8 - No relevant state information available */
        case TW_NO_INFO:
        /* 0x00 - Bus error due to an illegal START or STOP condition */
        case TW_BUS_ERROR:
        /* In case something else happened */
        default:
            /* Respond with RESET */
            TWCR = TWCR_RESET;
            break;
    }
}



/***** FUNCTIONS ******************************************************/

/*** INIT FUNCTIONS ***/
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
int main(void) {
    /*** Variables ***/
    
    /*** Initialize the hardware ***/
    /* GPIO */
    gpio_init();
    /* Timer/counter 1 */
    timer1_init();
    /* External interrupt */
    extint_init();
    /* I2C slave */
    i2c_slave_init(I2C_SLAVE_ADDRESS);
#if DEBUG_UART_ENABLE
    /* UART */
    uart_init();
#endif
    
    /* Enable interrupts */
    sei();
    
    /* Main Routine */
#if DEBUG_UART_ENABLE
    while (1) {
        if(*config & _BV(I2C_CONFIG_RDY)) {
            /*** Write the latest frequency measurement ***/
            /* First print the selected channel */
            uint8_t ch = (*config & I2C_CONFIG_CHSEL_MASK) >> I2C_CONFIG_CHSEL;
            uart_puts("CH");
            uart_putc(ch+'0');
            /* Second print the frequency */
            uint8_t resolution = (*config & I2C_CONFIG_RES_MASK) >> I2C_CONFIG_RES;
            uint32_t frequency = ((uint32_t)(*xmsb)<<16) | ((uint32_t)(*msb)<<8) | (uint32_t)(*lsb);
            uart_puts(" - Fmeas = ");
            uart_print_int(frequency);
            switch(resolution) {
                case 0:
                    uart_puts(" Hz\n");
                    break;
                case 1:
                    uart_puts(" kHz\n");
                    break;
                case 2:
                    uart_puts(" MHz\n");
                    break;
                }
        } else {
            uart_puts("No measurement available yet\n");
        }
        /* Wait for 1s */
        _delay_ms(1000);
    }
#else
    while(1);
#endif

    return(0);
}

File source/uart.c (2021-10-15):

/**
 *  Source file for AVR UART functionality.
 */

/***** INCLUDES ***************************************************************/
/* STD */
#include <stddef.h>
/* AVR */
#include <avr/io.h>
#include <avr/interrupt.h>
/* OWN */
#include "uart.h"


/***** MACROS *****************************************************************/
/*** UART CONFIG ***/
/* Macro to get the BAUD register value */
#define UBRR_VAL(bd)        ((F_CPU+bd*8)/(bd*16)-1)


/***** FUNCTIONS **************************************************************/
/*
 * Initialization of the UART
 */
void uart_init(void) {
    /* Set baudrate per default to 9600 */
    uart_set_baudrate(9600);
    
    /* Set the initial register values */
    UCSRA = 0x00;
    /* Set the framing (8N1) */
    UCSRC = _BV(URSEL) | _BV(UCSZ1) | _BV(UCSZ0);
    /* Enable RX and TX */
    UCSRB = _BV(RXEN) | _BV(TXEN);
}


/*
 * Set the UART baudrate
 */
void uart_set_baudrate(uint32_t baudrate) {
    /* Set the baudrate */
    UBRRH = UBRR_VAL(baudrate)>>8;
    UBRRL = UBRR_VAL(baudrate) & 0xFF;
}


/**************************************/
/***** BLOCKING ***********************/
/**************************************/

/*
 * Write a character via UART
 */
void uart_putc(char c) {
    /* Wait for transmit buffer to be empty */
    while(!(UCSRA & _BV(UDRE)));
    /* Write byte to the output buffer */
    UDR = c;
}


/*
 * Write a string via UART
 */
void uart_puts(char* s) {
    /* Transmit the string character by character */
    while(*s) {
        uart_putc(*s++);
    }
}

/*
 * Write data to the UART in blocking mode
 */
void uart_write_blocking(uint8_t* data, uint16_t len) {
    uint16_t i;
    /* Put the specified number of bytes in the TX buffer */
    for(i=0; i<len; i++) {
        /* Write the byte via UART */
        uart_putc(data[i]);
    }
}


/*
 * Read a character from UART
 */
uint8_t uart_getc(void) {
    /* Wait until reception is finished */
    while(!(UCSRA & _BV(RXC)));
    /* Return the received byte */
    return UDR;
}


/*
 * Read a string from UART
 */
void uart_gets(uint8_t* s, uint16_t len) {
    uint16_t index = 0;
    uint8_t temp;

    /* Read until string is finished or len is reached */
    do {
        /* Read next character */
        temp = uart_getc();
        /* Store character in string buffer */
        s[index++] = temp;
    } while((index < len) && (temp != '\n'));

    /* Make sure the string is null terminated */
    s[index] = '\0';
}

/* Print an integer number using putc only */
void uart_print_int(uint32_t value) {
    /* First, find the highest power of 10 */
    uint8_t digits = 0;
    uint32_t pow10 = 1;
    uint32_t tmp = value;
    while(tmp >= 10) {
        digits++;
        pow10 *= 10;
        tmp /= 10;
    }
    /* Second, print the digits of the number (from high to low) */
    while(pow10) {
        tmp = value / pow10;
        uart_putc(tmp+'0');
        value -= tmp * pow10;
        pow10 /= 10;
        /* Group digits ('.' before 3 digits) */
        if((digits%3 == 0) && (digits>0)) {
            uart_putc('.');
        }
        digits--;
    }
}

/* Print a byte in hexadecimal representation using putc only */
void uart_print_hex(uint8_t value) {
    /* Print preamble */
    uart_puts("0x");
    /* First, check the upper nibble */
    uint8_t tmp = (value&0xF0)>>4;
    if(tmp>9) {
        uart_putc('A'+(tmp-10));
    } else {
        uart_putc('0'+tmp);
    }
    /* Second, check the lower nibble */
    tmp = (value&0x0F);
    if(tmp>9) {
        uart_putc('A'+(tmp-10));
    } else {
        uart_putc('0'+tmp);
    }
}

/* Print a byte in binary representation using putc only */
void uart_print_binary(uint8_t value) {
    uint8_t i;
    for(i=0; i<8; i++) {
        if(value & (1 << (7-i))) {
            uart_putc('1');
        } else {
            uart_putc('0');
        }
    }
}

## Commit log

2021-10-15 Added background to schematic; added part description
2021-10-15 Added I2C slave description to README
2021-10-15 Added background to I2C CONFIG reg figure
2022-02-26 Added initial PCB design
    [SN74HC00PW.stp, SN74HC153PW.stp, SN74HC4040PW.stp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]
2022-02-26 Removed unintentional artefacts in 3D PCB visualization
2022-02-28 Updated PCB design Added board measurements Removed temp/cache files
    [frequency_counter.kicad_pcb]
